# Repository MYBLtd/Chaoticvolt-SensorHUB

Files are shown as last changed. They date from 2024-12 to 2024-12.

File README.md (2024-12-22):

# Chaoticvolt-SensorHUB

A robust ESP32-based temperature sensor hub with MQTT connectivity, web interface, and 7-segment display support.
The web interface allows for real-time temperature monitoring, relay control, and setting sensor firendly names. This also allows for quick diagnostics of the system the sensors are connected to without the need for a mqtt serer or any other external service.

Included are full PCB design files created in easyEDA and exported to Gerber files, Altium Designer Format and pdf for manufacturing.
The code uses FreeRTOS for task management and is written in C++ using the Espressiv framework in PlatformIO.

## Features

- Ethernet connectivity for reliable network communication
- MQTT integration with SSL/TLS security
- Real-time temperature monitoring with Dallas OneWire sensors
- Web dashboard for sensor visualization
- 7-segment LED display for local temperature readings
- Dual relay control with MQTT and web interface
- NTP time synchronization
- mDNS support for easy device discovery
- SPIFFS file system for web assets

## Hardware Requirements

- ESP32 EVB board
- Dallas OneWire temperature sensors (DS18B20)
- TM1637 7-segment display
- Two relay modules
- Ethernet connection

## Pin Configuration

```cpp
#define SYSTEM_RELAY1_PIN 32
#define SYSTEM_RELAY2_PIN 33
#define DISPLAY_CLK_PIN 16
#define DISPLAY_DIO_PIN 13

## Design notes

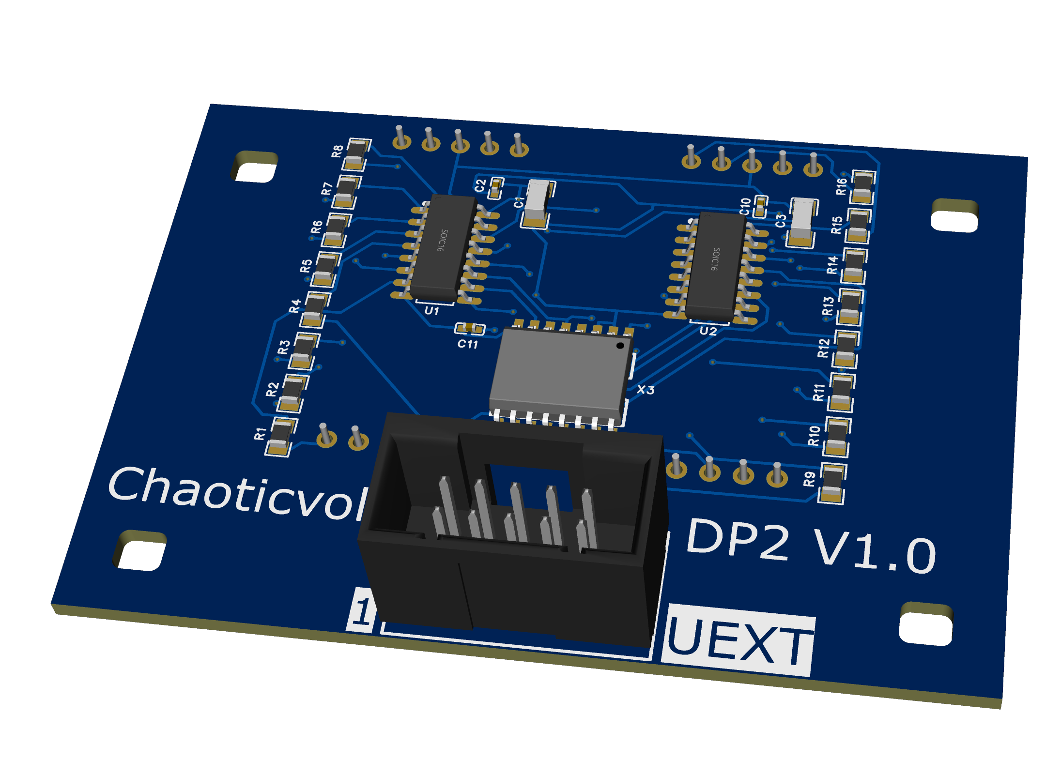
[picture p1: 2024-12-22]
pcb/3D_PCB_Choaticvolt_DP2_V1_2024-12-22-top.png

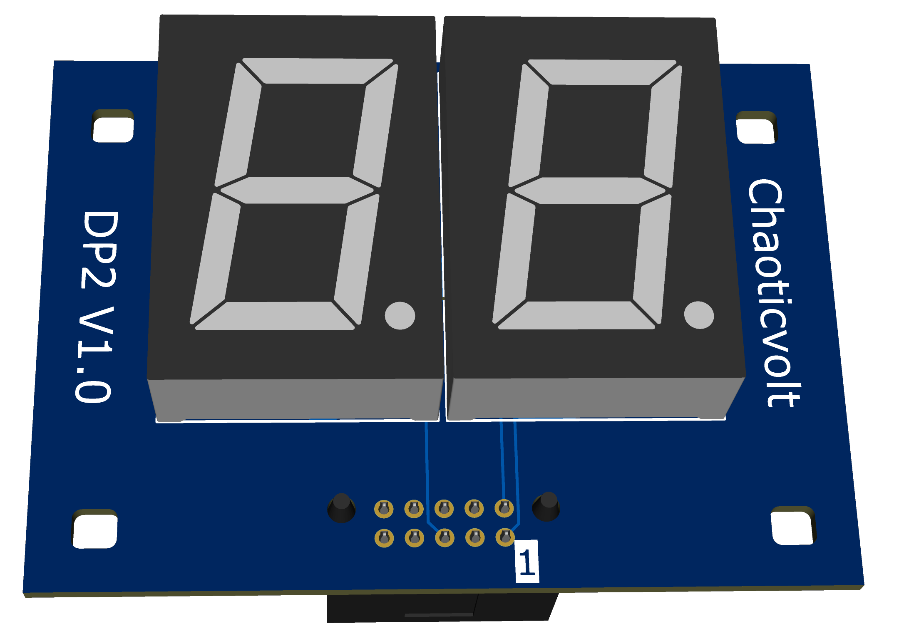
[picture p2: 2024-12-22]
pcb/3D_PCB_Choaticvolt_DP2_V1_2024-12-22-bottom.png

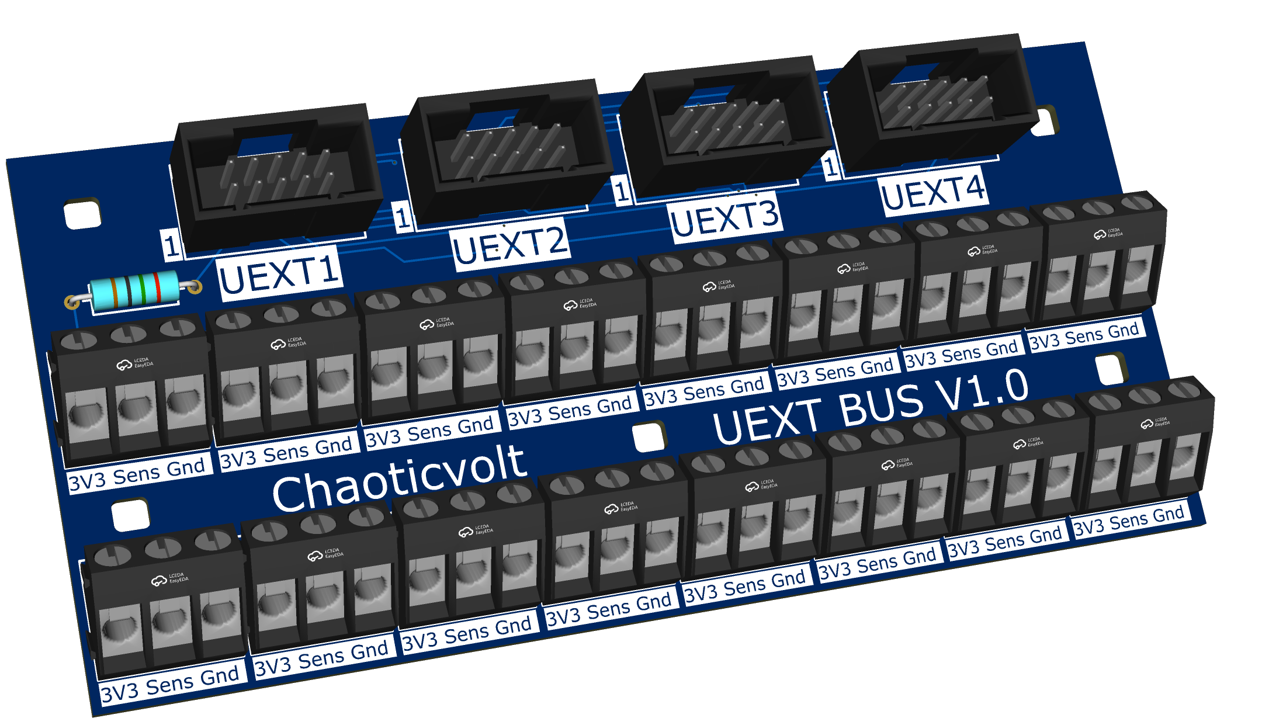
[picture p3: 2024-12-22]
pcb/3D_PCB_Choaticvolt_UCB1_V1_2024-12-22.png

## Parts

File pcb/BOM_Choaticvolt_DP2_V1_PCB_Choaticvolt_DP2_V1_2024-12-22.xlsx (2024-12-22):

No. | Quantity | Comment | Designator | Footprint | Value | Manufacturer Part | Manufacturer | Supplier Part | Supplier
1 | 2 | 47uF | C1,C3 | C1206 | 47uF | CL31A476MPHNNNE | SAMSUNG(三星) | C96123 | LCSC
2 | 3 | 100nF | C2,C10,C11 | C0402 | 100nF | CL05B104KO5NNNC | SAMSUNG(三星) | C1525 | LCSC
3 | 2 | SM411006N/15 | LED1,LED2 | LED-SEG-TH_10P-L24.0-W34.0-P2.54-S30.48-BL |  | SM411006N/15 | ARKLED(方舟) | C252204 | LCSC
4 | 16 | 120Ω | R1,R2,R3,R4,R5,R6,R7,R8,R9,R10,R11,R12,R13,R14,R15,R16 | R0805 | 120Ω | 0805W8F1200T5E | UNI-ROYAL(厚声) | C17437 | LCSC
5 | 2 | 74HC595D,118 | U1,U2 | SOIC-16_L9.9-W3.9-P1.27-LS6.0-BL |  | 74HC595D,118 | Nexperia(安世) | C5947 | LCSC
6 | 1 | 15477610 | UEXT1 | IDC-TH_15477610 |  | 15477610 | MOLEX | C293309 | LCSC
7 | 1 | PCF8574T/TR | X3 | SO-16_L10.3-W7.5-P1.27-LS10.3-BL |  | PCF8574T/TR | HGSEMI(华冠) | C2987288 | LCSC

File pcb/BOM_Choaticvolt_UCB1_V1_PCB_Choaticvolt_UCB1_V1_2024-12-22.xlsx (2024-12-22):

No. | Quantity | Comment | Designator | Footprint | Value | Manufacturer Part | Manufacturer | Supplier Part | Supplier
1 | 16 | 974-T-DS/03 | CN1,CN2,CN3,CN4,CN5,CN6,CN7,CN8,CN9,CN10,CN11,CN12,CN13,CN14,CN15,CN16 | CONN-TH_3P-P5.00_WECO_974-T-DS-03 |  | 974-T-DS/03 | WECO(威克德诺) | C2974863 | LCSC
2 | 1 | 2.7kΩ | R1 | RES-TH_BD3.3-L9.0-P13.00-D0.6 | 2.7kΩ | MFR1WSJT-52-2K7 | YAGEO(国巨) | C176423 | LCSC
3 | 4 | 15477610 | UEXT1,UEXT2,UEXT3,UEXT4 | IDC-TH_15477610 |  | 15477610 | MOLEX | C293309 | LCSC

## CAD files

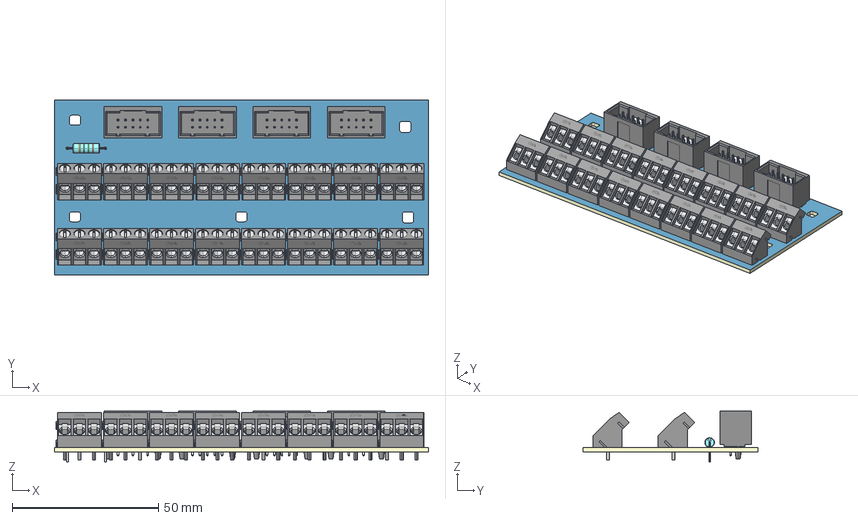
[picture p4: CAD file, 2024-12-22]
pcb/3D_PCB_Choaticvolt_UCB1_V1_2024-12-22.step
128.0 x 60.0 x 17.4 mm
TopTrack
BottomTrack
Board

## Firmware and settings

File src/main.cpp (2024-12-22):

#include <Arduino.h>
#include "freertos/FreeRTOS.h"
#include "freertos/task.h"
#include <WiFi.h>
#include <ETH.h>
#include <PubSubClient.h>
#include <NTPClient.h>
#include <WiFiUdp.h>
#include <time.h>
#include "esp_task_wdt.h"
#include "global_state.h"
#include "7segDisplay.h"  // Move this after global_state.h
#include "config.h"
#include "mqtt_manager.h"
#include "onewire_manager.h"
#include "webserver.h"  // Add this line
#include <SPIFFS.h>  // Add this include
#include <ESPmDNS.h>  // Add include at top

// SSL/Certificate Handling
#include <WiFiClientSecure.h>


// Add near top of file after includes
#define MQTT_BUFFER_SIZE 1024
#define SSL_BUFFER_SIZE 4096



// Global variables with careful memory management
WiFiClientSecure espClient;
PubSubClient mqttClient(espClient);
WiFiUDP ntpUDP;
NTPClient timeClient(ntpUDP, NTP_SERVER);
SegDisplay segDisplay(DISPLAY_CLK_PIN, DISPLAY_DIO_PIN);  // Add global instance

// Task Handles
TaskHandle_t mqttReconnectTaskHandle = NULL;
TaskHandle_t ntpUpdateTaskHandle = NULL;

// Function prototypes
void mqttTask(void *parameter);
void checkHeap();
void reconnectMQTT();
void setupEthernet();  // Add this line
void WiFiEvent(WiFiEvent_t event);  // Add this line
void initWebServer();  // Add this line

// Near other constants
#define STATE_TOPIC_PATH String(String(SYSTEM_NAME) + "/" + String(MQTT_CLIENT_ID) + "/" + String(MQTT_STATE_TOPIC))
#define SENSOR_TOPIC_PATH String(String(SYSTEM_NAME) + "/" + String(MQTT_CLIENT_ID) + "/" + String(MQTT_TOPIC_BASE))

// NTP Update Task with error handling
void ntpUpdateTask(void *pvParameters) {
    for (;;) {
        if (ETH.linkUp()) {
            timeClient.update();
            
            time_t epochTime = timeClient.getEpochTime();
            if (epochTime > 1000000000) {  // Basic sanity check
                struct tm* timeInfo = localtime(&epochTime);
                
                char timeBuffer[50];
                strftime(timeBuffer, sizeof(timeBuffer), "%Y-%m-%d %H:%M:%S", timeInfo);
                Serial.println("NTP Time: " + String(timeBuffer));
            } else {
                Serial.println("NTP Time Update Failed");
            }
        } else {
            Serial.println("Cannot Update NTP - Ethernet Down");
        }
        
        // Update every 2 minutes
        vTaskDelay(pdMS_TO_TICKS(120000));
    }
}

// Ethernet Event Handler
void WiFiEvent(WiFiEvent_t event) {
    static uint8_t reconnectAttempts = 0;
    
    switch (event) {
        case ARDUINO_EVENT_ETH_START:
            Serial.println("ETH Started");
            ETH.setHostname("esp32-ethernet");
            break;
            
        case ARDUINO_EVENT_ETH_CONNECTED:
            Serial.println("ETH Connected");
            break;
            
        case ARDUINO_EVENT_ETH_GOT_IP:
            reconnectAttempts = 0;  // Reset counter on successful connection
            Serial.print("ETH MAC: ");
            Serial.print(ETH.macAddress());
            Serial.print(", IPv4: ");
            Serial.print(ETH.localIP());
            Serial.print(", Subnet: ");
            Serial.print(ETH.subnetMask());
            Serial.print(", Gateway: ");
            Serial.println(ETH.gatewayIP());
            break;
            
        case ARDUINO_EVENT_ETH_DISCONNECTED:
            Serial.println("ETH Disconnected");
            if (++reconnectAttempts < MAX_RECONNECT_ATTEMPTS) {
                delay(RECONNECT_DELAY);
                // Trigger reconnection
                ETH.begin();
            } else {
                Serial.println("Max reconnection attempts reached. Restarting...");
                ESP.restart();
            }
            break;
            
        case ARDUINO_EVENT_ETH_STOP:
            Serial.println("ETH Stopped");
            break;
            
        default:
            Serial.printf("Unknown ETH event: %d\n", event);
            break;
    }
}

// Add this function before setup()
void setupEthernet() {
    // Initialize Ethernet event handler
    WiFi.onEvent(WiFiEvent);
    
    // Initialize ETH
    ETH.begin();
    
    // Wait for Ethernet connection (optional timeout)
    int timeout = 10; // 10 second timeout
    while (!ETH.linkUp() && timeout > 0) {
        Serial.println("Waiting for Ethernet connection...");
        delay(1000);
        timeout--;
    }
    
    if (!ETH.linkUp()) {
        Serial.println("Ethernet connection failed!");
        ESP.restart();
    }
    
    Serial.println("Ethernet connection established");
}

void setup() {
    // Initialize serial first for debugging
    Serial.begin(115200);
    
    // Initialize display early
    segDisplay.begin();
    segDisplay.showText("Init");
    
    // Start display task
    segDisplay.startDisplayTask();
    
    // Initialize Ethernet first
    setupEthernet();
    
    // Wait for network
    while (!ETH.linkUp()) {
        delay(100);
    }
    
    if(!SPIFFS.begin(true)) {
        Serial.println("SPIFFS Mount Failed");
        return;
    }
    
    // Initialize mDNS
    if (MDNS.begin("sensorhub")) {
        Serial.println("MDNS responder started");
        
        // Add service to mDNS
        MDNS.addService("http", "tcp", 80);
        MDNS.addService("mqtt", "tcp", MQTT_PORT);
        
        // Add TXT records
        MDNS.addServiceTxt("mqtt", "tcp", "manufacturer", "ChaoticVolt");
        MDNS.addServiceTxt("mqtt", "tcp", "model", "SensorHUB");
        MDNS.addServiceTxt("mqtt", "tcp", "version", "1.0");
    } else {
        Serial.println("Error setting up MDNS responder");
    }

    // Create web server task
    xTaskCreatePinnedToCore(
        [](void* parameter) {
            webServer.begin();
            for(;;) {
                vTaskDelay(pdMS_TO_TICKS(100));
            }
        },
        "WebTask",
        8192,        // Larger stack
        NULL,
        2,          // Higher priority
        NULL,
        1          // Run on core 1
    );
    
    // Initialize OneWire before MQTT
    initOneWire();
    
    // Start MQTT manager last
    MQTTManager::getInstance().begin();
    
    // Create sensor tasks
    xTaskCreatePinnedToCore(
        TaskReadTemperature,
        "TempTask",
        4096,
        NULL,
        1,  // Lower priority
        NULL,
        0   // Core 0
    );
    
    xTaskCreatePinnedToCore(
        TaskScanSensors,
        "ScanTask",
        4096,
        NULL,
        1,  // Lower priority
        NULL,
        0   // Core 0
    );
}

// Add new function before loop()
void publishState() {
    static uint32_t lastPublish = 0;
    const uint32_t now = millis();
    
    if (now - lastPublish >= STATE_PUBLISH_INTERVAL) {
        char state[128];
        snprintf(state, sizeof(state),
                "{\"heap\":%d,\"uptime\":%lu,\"connected\":%d}",
                ESP.getFreeHeap(),
                now / 1000, // Uptime in seconds
                mqttClient.connected());
                
        mqttClient.publish(STATE_TOPIC_PATH.c_str(), state, true); // Retained message
        lastPublish = now;
    }
}

// Minimal loop since tasks handle the work
void loop() {
    vTaskDelay(pdMS_TO_TICKS(1000));  // Prevent watchdog triggers
}

// In your loop or task function
void checkHeap() {
    static uint32_t lastCheck = 0;
    const uint32_t CHECK_INTERVAL = 30000; // Check every 30 seconds
    
    if (millis() - lastCheck >= CHECK_INTERVAL) {
        uint32_t freeHeap = ESP.getFreeHeap();
        Serial.printf("Free heap: %u bytes\n", freeHeap);
        lastCheck = millis();
        
        if (freeHeap < 20000) {
            Serial.println("WARNING: Low memory condition!");
        }
    }
}

void mqttTask(void *parameter) {
    static uint32_t lastHeapCheck = 0;
    const TickType_t xDelay = pdMS_TO_TICKS(100);
    
    // Get reference to MQTTManager instance
    MQTTManager& mqttManager = MQTTManager::getInstance();
    
    for(;;) {
        if (!mqttManager.isConnected()) {
            mqttManager.reconnectWithBackoff();
        }
        
        mqttManager.loop();
        
        // Check heap every 5 seconds
        if (xTaskGetTickCount() - lastHeapCheck > pdMS_TO_TICKS(5000)) {
            checkHeap();
            lastHeapCheck = xTaskGetTickCount();
        }
        
        vTaskDelay(xDelay);
    }
}

// Add this function before setup()
void initWebServer() {
    webServer.setMQTTManager(&MQTTManager::getInstance());
    webServer.begin();
}

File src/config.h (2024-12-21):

#ifndef CONFIG_H
#define CONFIG_H

// MQTT Broker Configuration
#define SYSTEM_NAME "JuRo"
#define MQTT_CLIENT_ID "Sensor_HUB01"
#define MQTT_TOPIC_BASE "sensors"
#define MQTT_STATE_TOPIC "state"
#define MQTT_BROKER "mq.cemco.nl"
#define MQTT_RELAY1_SET_TOPIC "relay1"
#define MQTT_RELAY2_SET_TOPIC "relay2"
#define MQTT_PORT 12883
#define MQTT_USERNAME "Redbreast"
#define MQTT_PASSWORD "pdMEoHHwRKqIKspOWoC9JZ60P5"
#define WEBPAGE_HIGHLITED_SENSOR "28104a482819015c"
#define SYSTEM_RELAY1_TOPIC "relay1"
#define SYSTEM_RELAY2_TOPIC "relay2"

// Pin configurations
#define SYSTEM_RELAY1_PIN 32
#define SYSTEM_RELAY2_PIN 33
#define DISPLAY_CLK_PIN 16
#define DISPLAY_DIO_PIN 13

// Increased stack sizes and added some safeguards
#define MQTT_RECONNECT_STACK_SIZE 6144  // Increased from 4096
#define NTP_UPDATE_STACK_SIZE 4096
#define MQTT_RECONNECT_INTERVAL 15000   // 15 seconds between reconnection attempts
#define MAX_RECONNECT_ATTEMPTS 5
#define RECONNECT_DELAY 5000  // 5 seconds

// OneWire & Temperature Sensor Configuration
const uint8_t ONE_WIRE_BUS = 4;          // GPIO pin 4
const uint8_t MAX_SENSORS = 12;          // Max number of sensors
const uint32_t SCAN_INTERVAL_MS = 12000; // milliseconds
const uint32_t READ_INTERVAL_MS = 6000;  // milliseconds

// Increase task stack sizes
#define MQTT_TASK_STACK_SIZE (8192)
#define DEFAULT_TASK_PRIORITY (1)
#define MQTT_TASK_PRIORITY (2)        // Higher than default
#define ONEWIRE_TASK_PRIORITY (1)     // Standard priority

// NTP Configuration
#define NTP_SERVER "2.europe.pool.ntp.org"
#define GMT_OFFSET_SEC 3600     // +1 hour
#define DAYLIGHT_OFFSET_SEC 3600 // +1 hour DST

// Buffer sizes
#define MQTT_BUFFER_SIZE 1024
#define SSL_BUFFER_SIZE 4096


// Modify existing or add new timing constants
#undef STATE_PUBLISH_INTERVAL
#undef SENSOR_PUBLISH_INTERVAL

static constexpr uint32_t STATE_PUBLISH_INTERVAL = 4000;   // 4 seconds
static constexpr uint32_t SENSOR_PUBLISH_INTERVAL = 4000;  // 4 seconds

#endif

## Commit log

2024-12-20 sensors column in webpage working
2024-12-20 layout mostly fixed, no temp graph and no mqtt publishing
    [webserver.cpp]
2024-12-20 cosmetic fix relay control
2024-12-21 V0.0 working
    MQTT remote publishing works, Webpage works, 7seg display works, relay switching works, mDNS works.
2024-12-21 Added friendly sensor names
    implementation:
    * Frontend sends names via /api/sensor/name
    * Backend stores in Preferences
    * Names should persist in
    * Names should load from Preferences on startup
2024-12-22 fixed sensor naming not persistent
    [main.cpp, onewire_manager.cpp, webserver.cpp]
2024-12-22 added pcb files
